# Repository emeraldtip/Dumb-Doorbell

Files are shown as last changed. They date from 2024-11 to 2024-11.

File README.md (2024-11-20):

# Dumb Doorbell

The ELEC-C9801 Design Thinking and Electronic prototyping final project for Team#18

## Installing/uploading code

### Generating the .bat scripts for easier installation
Run "python generate-bast.py" and follow the instructions.
This is done, as otherwise if a single team member would edit a bat script to change the com port, if they pushed their changes, the com port would change for everyone else aswell, which is not wanted.

### Flashing the ESP32

Use the install-micropython.bat file to flash micropython onto the ESP32, if you don't have micropython on the controller yet.
Make sure to edit the .bat file to point to the correct COM port (check in your device manager under "Ports (COM & LPT)")

### Uploading python code to the ESP32

Use the write-to-ESP.bat files in the directories of the respective devices (main doorbell and wristband) to upload the code to the ESP32.
Make sure to edit the .bat file to point to the correct COM port (in Windows check in your device manager under "Ports (COM & LPT)")
Upload the microdot and utemplate libraries to the doorbell as well using: ```python ../tools-and-binaries/pyboard.py --device [serial-port-here] -f cp microdot.py :``` and ```python ../tools-and-binaries/pyboard.py --device [serial-port-here] -f cp utemplate.py :```

### Encryption

- Create 2 16-byte strings to store the encryption keys.
- Put them in a file called "keys.txt" in the doorbell folder and switch into it
- Copy the "keys.txt" file to the ESP using: ```python ../tools-and-binaries/pyboard.py --device [serial-port-here] -f cp keys.txt :```
- Make another copy of the keys.txt file into the wristband folder
- Use the same command to copy the keys over to the ESP: ```python ../tools-and-binaries/pyboard.py --device [serial-port-here] -f cp keys.txt :```

## Credits:
- [microdot](https://github.com/miguelgrinberg/microdot) by [miguelgrinberg](https://github.com/miguelgrinberg/) as the web framework 
- [utemplate](https://github.com/miguelgrinberg/microdot) by [pfalcon](https://github.com/pfalcon) as the template engine used with microdot
- [ffmpeg.wasm](https://github.com/ffmpegwasm/ffmpeg.wasm) by [ffmpeg.wasm](https://github.com/ffmpegwasm) for converting audio files into 8 bit bit depth in the browser

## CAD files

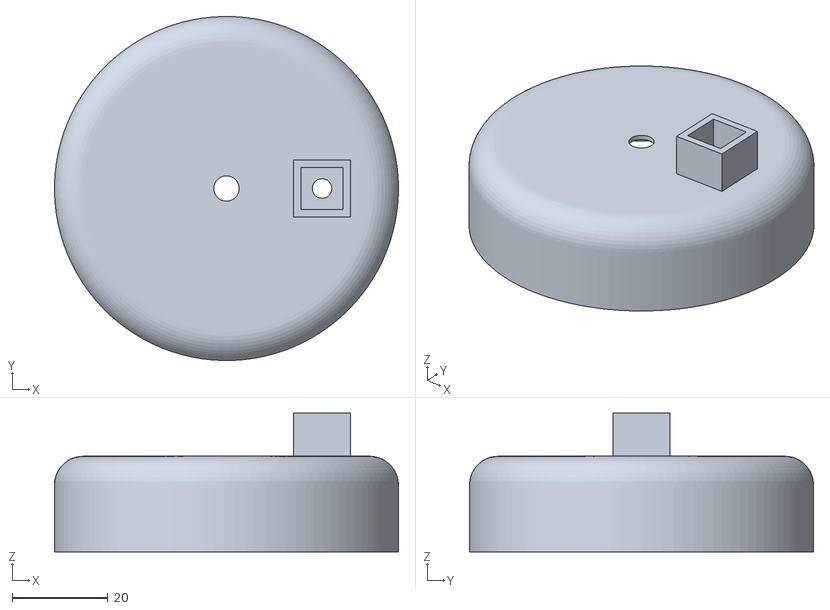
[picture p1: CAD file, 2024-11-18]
models/dumb_doorbell/dumb_doorbell.stl
72.0 x 72.0 x 29.0

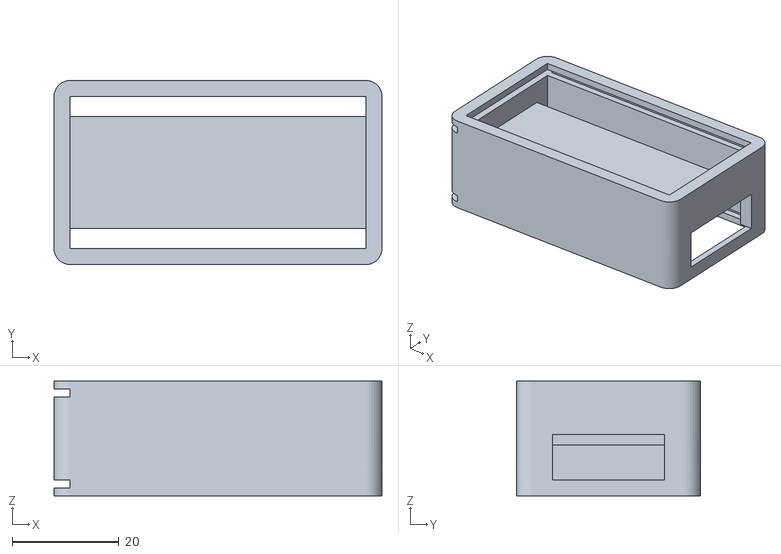
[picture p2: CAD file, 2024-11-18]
models/ESP_32_Case/ESP_32_Case.stl
61.5 x 34.5 x 21.5

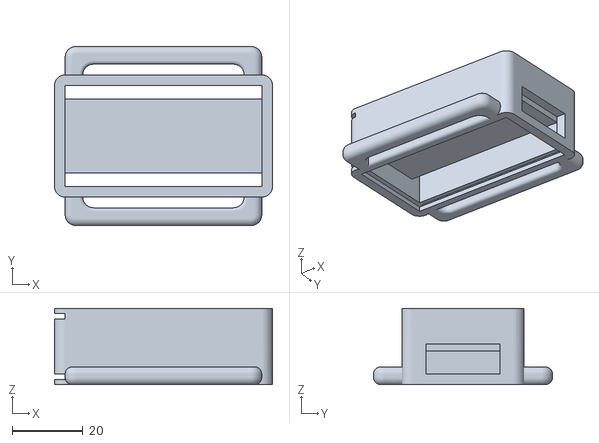
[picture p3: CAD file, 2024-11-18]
models/ESP_32_Case_Handled/ESP_32_Case_Handled.stl
61.5 x 50.5 x 21.5

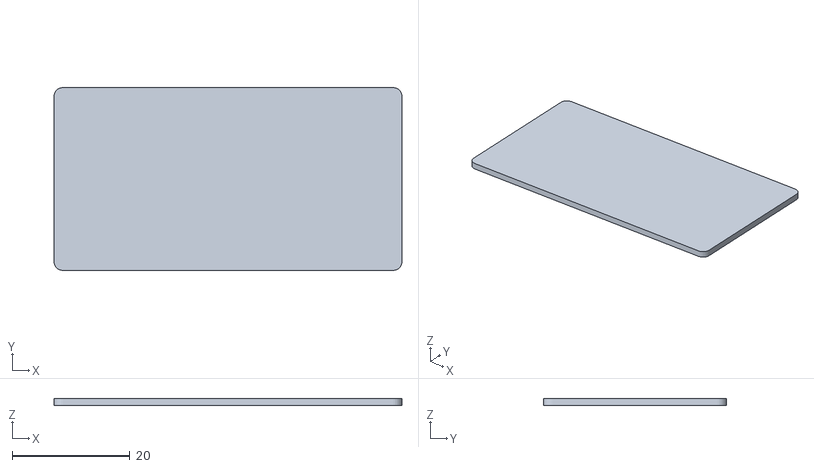
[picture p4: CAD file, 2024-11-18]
models/ESP_32_Lid/ESP_32_Lid.stl
59.0 x 31.0 x 1.25

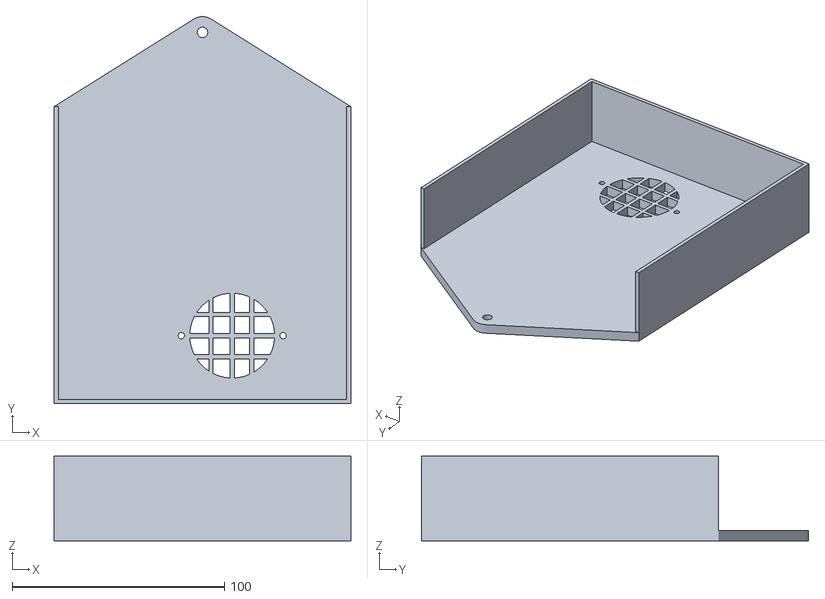
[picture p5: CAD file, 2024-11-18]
models/external_cover/external_cover.stl
140.0 x 182.5 x 40.0

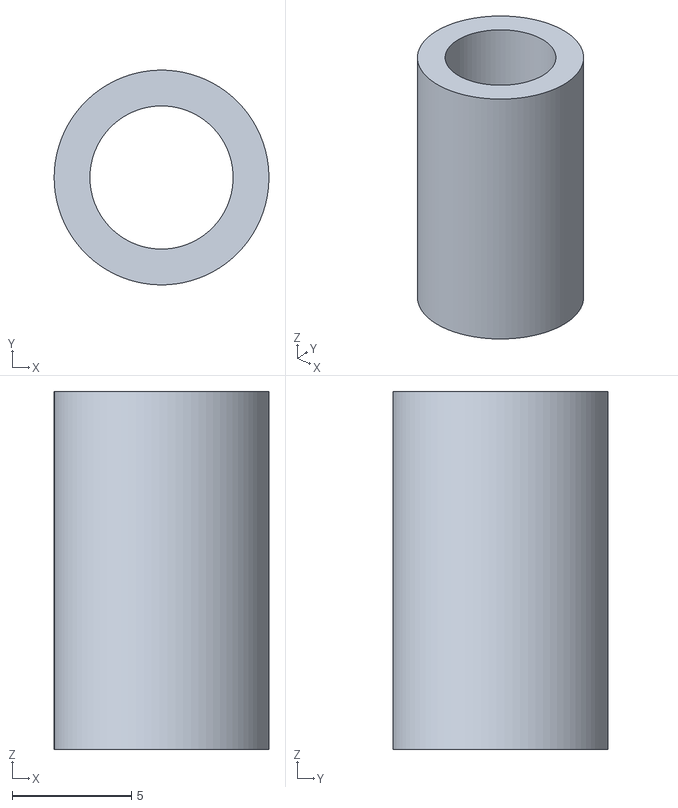
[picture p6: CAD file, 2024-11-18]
models/spacer/spacer.stl
9.00 x 9.00 x 15.0

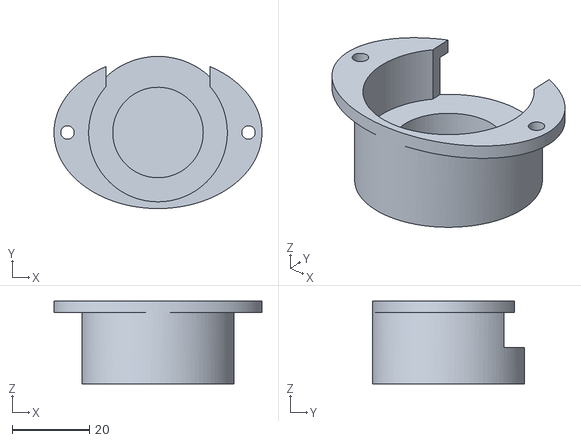
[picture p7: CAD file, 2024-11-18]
models/speaker_holder/speaker_holder.stl
54.0 x 39.5 x 21.5

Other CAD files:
models/ESP_32_Case/ESP_32_Case.f3d
models/ESP_32_Case_Handled/ESP_32_Case.f3d
models/ESP_32_Case_Handled/ESP_32_Case_Handled.f3d
models/ESP_32_Lid/ESP_32_Lid.f3d
models/dumb_doorbell/dumb_doorbell.f3d
models/external_cover/external_cover.f3d
models/spacer/spacer.f3d
models/speaker_holder/speaker_holder.f3d

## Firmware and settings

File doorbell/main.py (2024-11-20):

import struct
import asyncio
import network
import espnow
import os
import random
import json
from machine import Pin, I2S
from microdot import Microdot, send_file, Request
from utemplater import Template
import gc


#Webserver init variable
app = Microdot()
Request.max_content_length = 1024 * 1024

#Global variables
filename = "sound.wav"
volume = 0.5
pattern = 1.0
samplerate = 11025

#Button
button_pin = Pin(23,Pin.IN,Pin.PULL_UP)

#Audio
sck_pin = Pin(14)   # Serial clock output
ws_pin = Pin(13)    # Word clock output
sd_pin = Pin(12)    # Serial data output

#File opening logic
wav = open(filename, "rb")

#WIFI init logic
ap = network.WLAN(network.AP_IF)
ap.active(True)

ssid, pw = "", ""
if "wifi.txt" in os.listdir():
    with open("wifi.txt","r") as file:
        ssid, pw = file.readlines()
else:
    ssid = "Dumb Doorbell"
    pw = "".join(random.choice(
    "QWERTYUIOPASDFGHJKLZXCVBNM1234567890qwertyuiopasdfghjklzxcvbnm_!+-"
    ) for i in range(8)) #random 8-chracter password generation
    with open("wifi.txt","w") as file:
        file.write(ssid+"\n"+pw)

print("SSID=",ssid)    
print("Password=",pw)
ap.config(essid=ssid, password=pw, security=3) #3 - WPA2_PSK authentication



#ESP-NOW init logic
interface = espnow.ESPNow()
interface.active(True)
peer = b"\xcc\x7b\x5c\x9a\xf1\xfc" # MAC address of wristband

#encryption keys
if "keys.txt" in os.listdir():
    with open("keys.txt","r") as file:
        pmk, lmk = file.readlines() #read primary and local master keys
        interface.set_pmk(pmk.strip()) #strip for whitespace removal just in case
        interface.add_peer(peer, ifidx=network.AP_IF, lmk=lmk.strip(), encrypt=True)
        print("Using encryption")    
else:
    #non-encrypted
    interface.add_peer(peer, ifidx=network.AP_IF)    
    print("Non-encrypted")



#Load settings from previous session
if "settings.txt" in os.listdir():
    with open("settings.txt","r") as file:
        volume, settings = [float(i) for i in file.readlines()]
        print(volume,settings)
    print("read")


wav_samples_final = memoryview(bytearray(512))
#audio file playing logic
async def play_ringtone():
    #clear ram
    gc.collect()
   
    global wav
    global volume
    global wav_samples_final
    global samplerate
    global bits_per_sample

    await asyncio.sleep_ms(1)

    #Open I2S stream
    audio_out = I2S(0, sck=sck_pin, ws=ws_pin, sd=sd_pin,mode=I2S.TX, bits=16, format=I2S.MONO, rate=samplerate, ibuf=5120)
        

    #seek past the header of the file to the audio data
    pos = wav.seek(44)
    
    while True:
        
        read_bytes = ""
        try:
            read_bytes = wav.read(512)
        except:
            pass
            
        if len(read_bytes) != 0:
            #convert bytes to integers, reduce amplitude, then multiply by volume and the put into bytearray
            e = 0
            for i in struct.unpack("B"*len(read_bytes),read_bytes):
                wav_samples_final[e] = int((i-128)*volume*2)
                e+=1
            #print("writing")
            audio_out.write(wav_samples_final)
            await asyncio.sleep_ms(1)
        else:
            break

    wav.close()
    audio_out.deinit()








#web code:
@app.route("/")
async def index(request):
    global volume
    vol = int(volume*100)
    return Template("index.html").render(vol=vol), {'Content-Type': 'text/html'}

#static file routing
@app.route('/static/<path:path>')
async def static(request, path):
    if '..' in path:
        # directory traversal is not allowed
        return 'Not found', 404
    if "ffmpeg" in path:
        return send_file('static/' + path, compressed=True)
    return send_file('static/' + path)

#updating parameters
@app.post('/update',)
async def updet(request):
    global volume
    global pattern
    
    print("update")
    if request.method == "POST":
        data = request.json
        print(data)
        if len(data) != 0:
            vol = int(data.get("volume"))
            patt = int(data.get("pattern"))
            reset = int(data.get("reset"))
            print(vol)
            print(patt)
            print(reset)
            if reset == 0:
                print("dontreset")
                volume = vol/100
                pattern = patt
            else:
                print("reset")
                volume = 0.5
                pattern = 1.0
            with open("settings.txt","w+") as file:
                file.write(str(volume)+"\n"+str(pattern))
    return json.dumps({"success":True,"message":"Successfully updated!"}), 200, {'ContentType':'application/json'}

#file upload bs
@app.post('/upload')
async def upload(request):
    # obtain the filename and size from request headers
    filename = request.headers['Content-Disposition'].split(
        'filename=')[1].strip('"')
    size = int(request.headers['Content-Length'])


    # write the file to the files directory in 1K chunks
    with open("sound.wav", 'wb') as f:
        while size > 0:
            chunk = await request.stream.read(min(size, 1024))
            f.write(chunk)
            size -= len(chunk)

    print('Successfully saved file: ' + filename)
    return ''







#mainloop
async def check_button():
    global wav
    global filename
    global interface
    global samplerate
    global bits_per_sample
    
    if button_pin.value() == 0:
        #(re)open file
        wav = open(filename, "rb")
        #seek to read the samplerate
        wav.seek(24)
        samplerate = int.from_bytes(wav.read(4),"little")
        print("Samplerate:",samplerate)
        #seek to beginning of data
        wav.seek(44)
        if pattern == 1.0:
            interface.send(peer, "ring")
        elif pattern == 2.0:
            interface.send(peer, "tone")
        print("registered")
        
        #wait before registering next button press
        await asyncio.sleep_ms(300)
        asyncio.create_task(play_ringtone())
    else:
        pass

asyncio.create_task(app.start_server(port=80))
while True:
    asyncio.run(check_button())

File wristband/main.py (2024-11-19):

import time
import network
import espnow
import os
from machine import Pin
import re


vibr = Pin(13, Pin.OUT)
button = Pin(25 , Pin.IN, Pin.PULL_UP)

flag = False #Using the variable as
#if you just read the value of the pin from the ESP, it will always read 0
#as the vibration motor pulls too much current and pulls the voltage
#of the pin too low

#WIFI setup for ESP-NOW
net = network.WLAN(network.STA_IF)
net.active(True)

#ESP-NOW setup
interface = espnow.ESPNow()
interface.active(True)
peer = b'\x30\xae\xa4\x76\x23\x21' # MAC address of doorbell

#encryption keys
if "keys.txt" in os.listdir():
    with open("keys.txt","r") as file:
        print('using encryption')
        pmk, lmk = file.readlines() #read primary and local master keys
        interface.set_pmk(pmk.strip())
        interface.add_peer(peer, ifidx=network.STA_IF, lmk=lmk.strip(), encrypt=True)      
else:
    #non-encrypted
    interface.add_peer(peer, ifidx=network.STA_IF)    


def toggle(pin: Pin):
    global flag

    pin.value(flag)
    print("toggled",flag)
    flag = not flag


while True:
    host, msg = interface.recv()
    if msg: #If no message is received then msg=None
        print(host.hex(), msg)
        interface.send(peer, "received")
        
        message = str(msg).strip("b'")
#        if bool(re.match('^[-. ]*$',message[1])):
#            for i in message:
#                if i==' ': 
#                    vibr.off()
#                    time.sleep(1.5)
#
#                elif i == '-':
#                    vibr.on()
#                    time.sleep(1.5)
#                    vibr.off()
#                elif i == '.':
#                    vibr.on()
#                    time.sleep(0.5)
#                    vibr.off()
#                if button.value() == 0: break
        if msg == b"ring":
            counter = 20
            while counter>0 :
                vibr.value(1)
                time.sleep(0.5)
                counter-=1
                if button.value() == 0: break
            vibr.value(0)
        elif msg == b"tone":
            counter = 10
            while counter>0:
                for x in range(1,3):
                    vibr.value(1)
                    time.sleep(1)
                    vibr.off()
                    time.sleep(0.5)
                    counter -=1
                if button.value() == 0: break


        

#while True:
#    toggle(vibr)
#    time.sleep(1)

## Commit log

2024-10-24 Initial Commit, test Button reading code done
2024-10-24 Initial buzzer prototype done
    [main.py]
2024-10-30 Added models folder and contents
    [dumb_doorbell v0.stl]
2024-10-30 Added the Autodesk Fusion model
    [dumb_doorbell v0.f3d]
2024-10-31 Models v1
    [dumb_doorbell v1.f3d, dumb_doorbell v1.stl]
2024-10-31 Overwrote failed print
2024-11-01 Added ESP 32 Case
    [ESP 32 Case v1.f3d, ESP 32 Case v1.stl, ESP 32 Lid v0.f3d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]
2024-11-11 Audio no longer obnoxious
    [main.py]
2024-11-12 Button press detection implemented
2024-11-12 Fixed vibration pin toggling
    [main.py]
2024-11-12 fixed errors when restarting audio playbcak
    [main.py]
2024-11-13 The wristband now vibrates when the doorbell is rang
    [main.py]
2024-11-14 add button to turn off
2024-11-14 Fixed button presses not working after a while
    [generate-bats.py, main.py]
2024-11-14 read morse message and create vibrate pattern
    [main.py]
2024-11-14 Volume changing from web implemented (memory issues fixed (for now))
    [generate-bats.py, main.py]
2024-11-15 Reduced I2S ibuf size to hopefully ease memory issues
    [main.py]
2024-11-18 Added new models, ESP cases, outer casing, and a new doorbell cover
    [ESP 32 Case Handled v2.f3d, ESP 32 Case Handled v2.stl, ESP 32 Case v6 v2.f3d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]
2024-11-18 Restructuring - First revision of models
    [ESP 32 Case Handled v2.f3d, ESP 32 Case Handled v2.stl, ESP 32 Case v6 v2.f3d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]
2024-11-18 Dumb doorbell v0 -> v1
    [dumb_doorbell.f3d, dumb_doorbell.stl]
2024-11-18 Dumb doorbell v1 -> v3
    [dumb_doorbell.f3d, dumb_doorbell.stl]
2024-11-18 ESP 32 Case v1 -> v6
    [ESP 32 Case.f3d, ESP 32 Case.stl]
2024-11-18 Added ESP 32 Case Handled files
    [ESP 32 Case Handled.f3d, ESP 32 Case Handled.stl]
2024-11-18 ESP 32 Lid v0 -> v5
    [ESP 32 Lid.f3d, ESP 32 Lid.stl]
2024-11-18 Added Speaker holder files
    [speaker_holder.f3d, speaker_holder.stl]
2024-11-18 Added External cover files
    [external cover.f3d, external cover.stl]
2024-11-18 Added spacer files
    [spacer.f3d, spacer.stl]
2024-11-18 Moved separate parts into folders, restructure complete
    [ESP_32_Case.f3d, ESP_32_Case.stl, ESP_32_Case_Handled.f3d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]
2024-11-18 Settings now save to a file and stay between reboots
    [main.py]
2024-11-19 Multiple vibration pattersn added
    [main.py]
2024-11-19 Fixed pattern 2 not stopping when acknowledged
    [main.py]
2024-11-19 Failed attempt at getting pcm 16 files to play
    [main.py]
